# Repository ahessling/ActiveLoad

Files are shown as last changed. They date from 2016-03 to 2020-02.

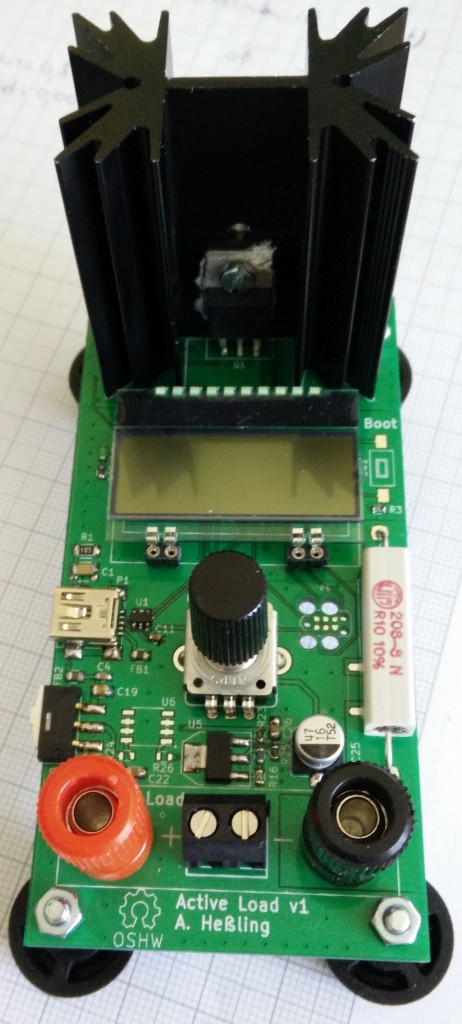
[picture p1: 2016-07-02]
active-load-v1-top.jpg

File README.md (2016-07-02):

# Active Load with microcontroller
This repository contains the hardware design, the firmware and the GUI software of my active load device.



Features:
* Power supply from around 3.3V to 40V
* Should be powered by device under test
* Alternative power supply via USB
* Maximum dissipated power: Around 12W permanently at room temperature
* Maximum current: 3A
* Robust (protected from overvoltage, overcurrent and overtemperature conditions)
* Device under test should be connected via banana plugs or screw terminals
* A PC should be able to monitor the actual current and control the desired current via USB
* Small display to monitor actual and setpoint current
* Rotary encoder to change setpoint current
* Small (5×10 cm)
* Measure temperature at heatsink

The whole design process with a lot of details are written down [in my blog](http://blog.andrehessling.de/2016/02/07/project-active-load-with-microcontroller-part-1-requirements/).

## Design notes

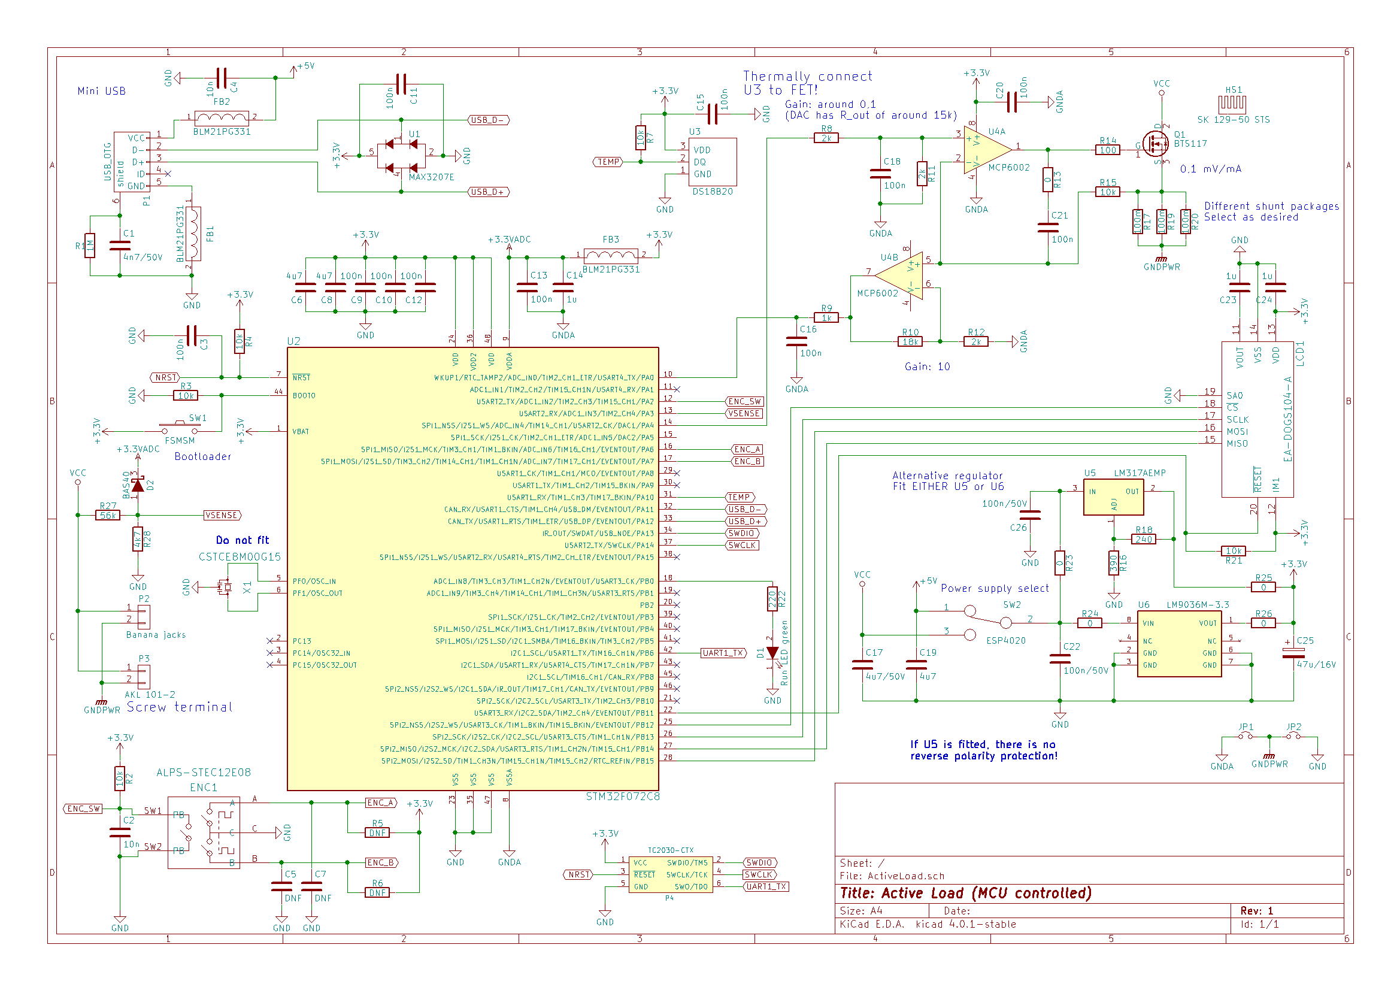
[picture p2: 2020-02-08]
Hardware/Schematic/Export/ActiveLoad_v1-schematic.png

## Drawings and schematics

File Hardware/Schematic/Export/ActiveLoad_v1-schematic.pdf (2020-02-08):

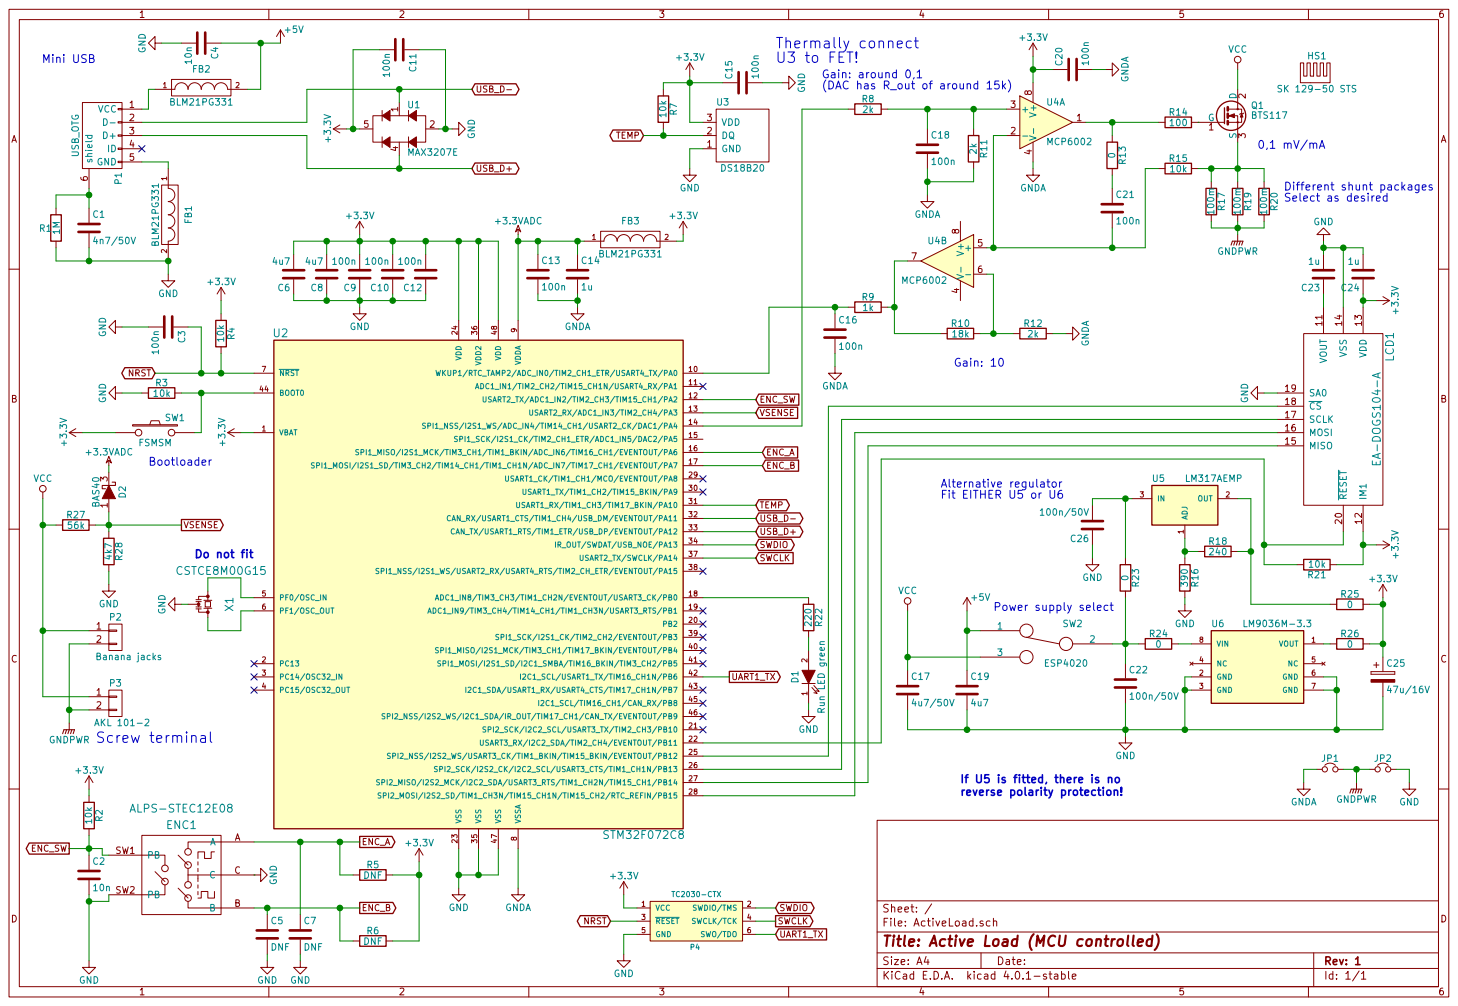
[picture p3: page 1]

reverse polarity protection! Do not fit
CSTCE8M00G15 GND

0 Power supply select GNDPWR

1 2 D1 Run LED green 220 R22 GND

If U5 is fitted, there is no

Id: 1/1 Title: Active Load (MCU controlled) File: ActiveLoad.sch Sheet: /

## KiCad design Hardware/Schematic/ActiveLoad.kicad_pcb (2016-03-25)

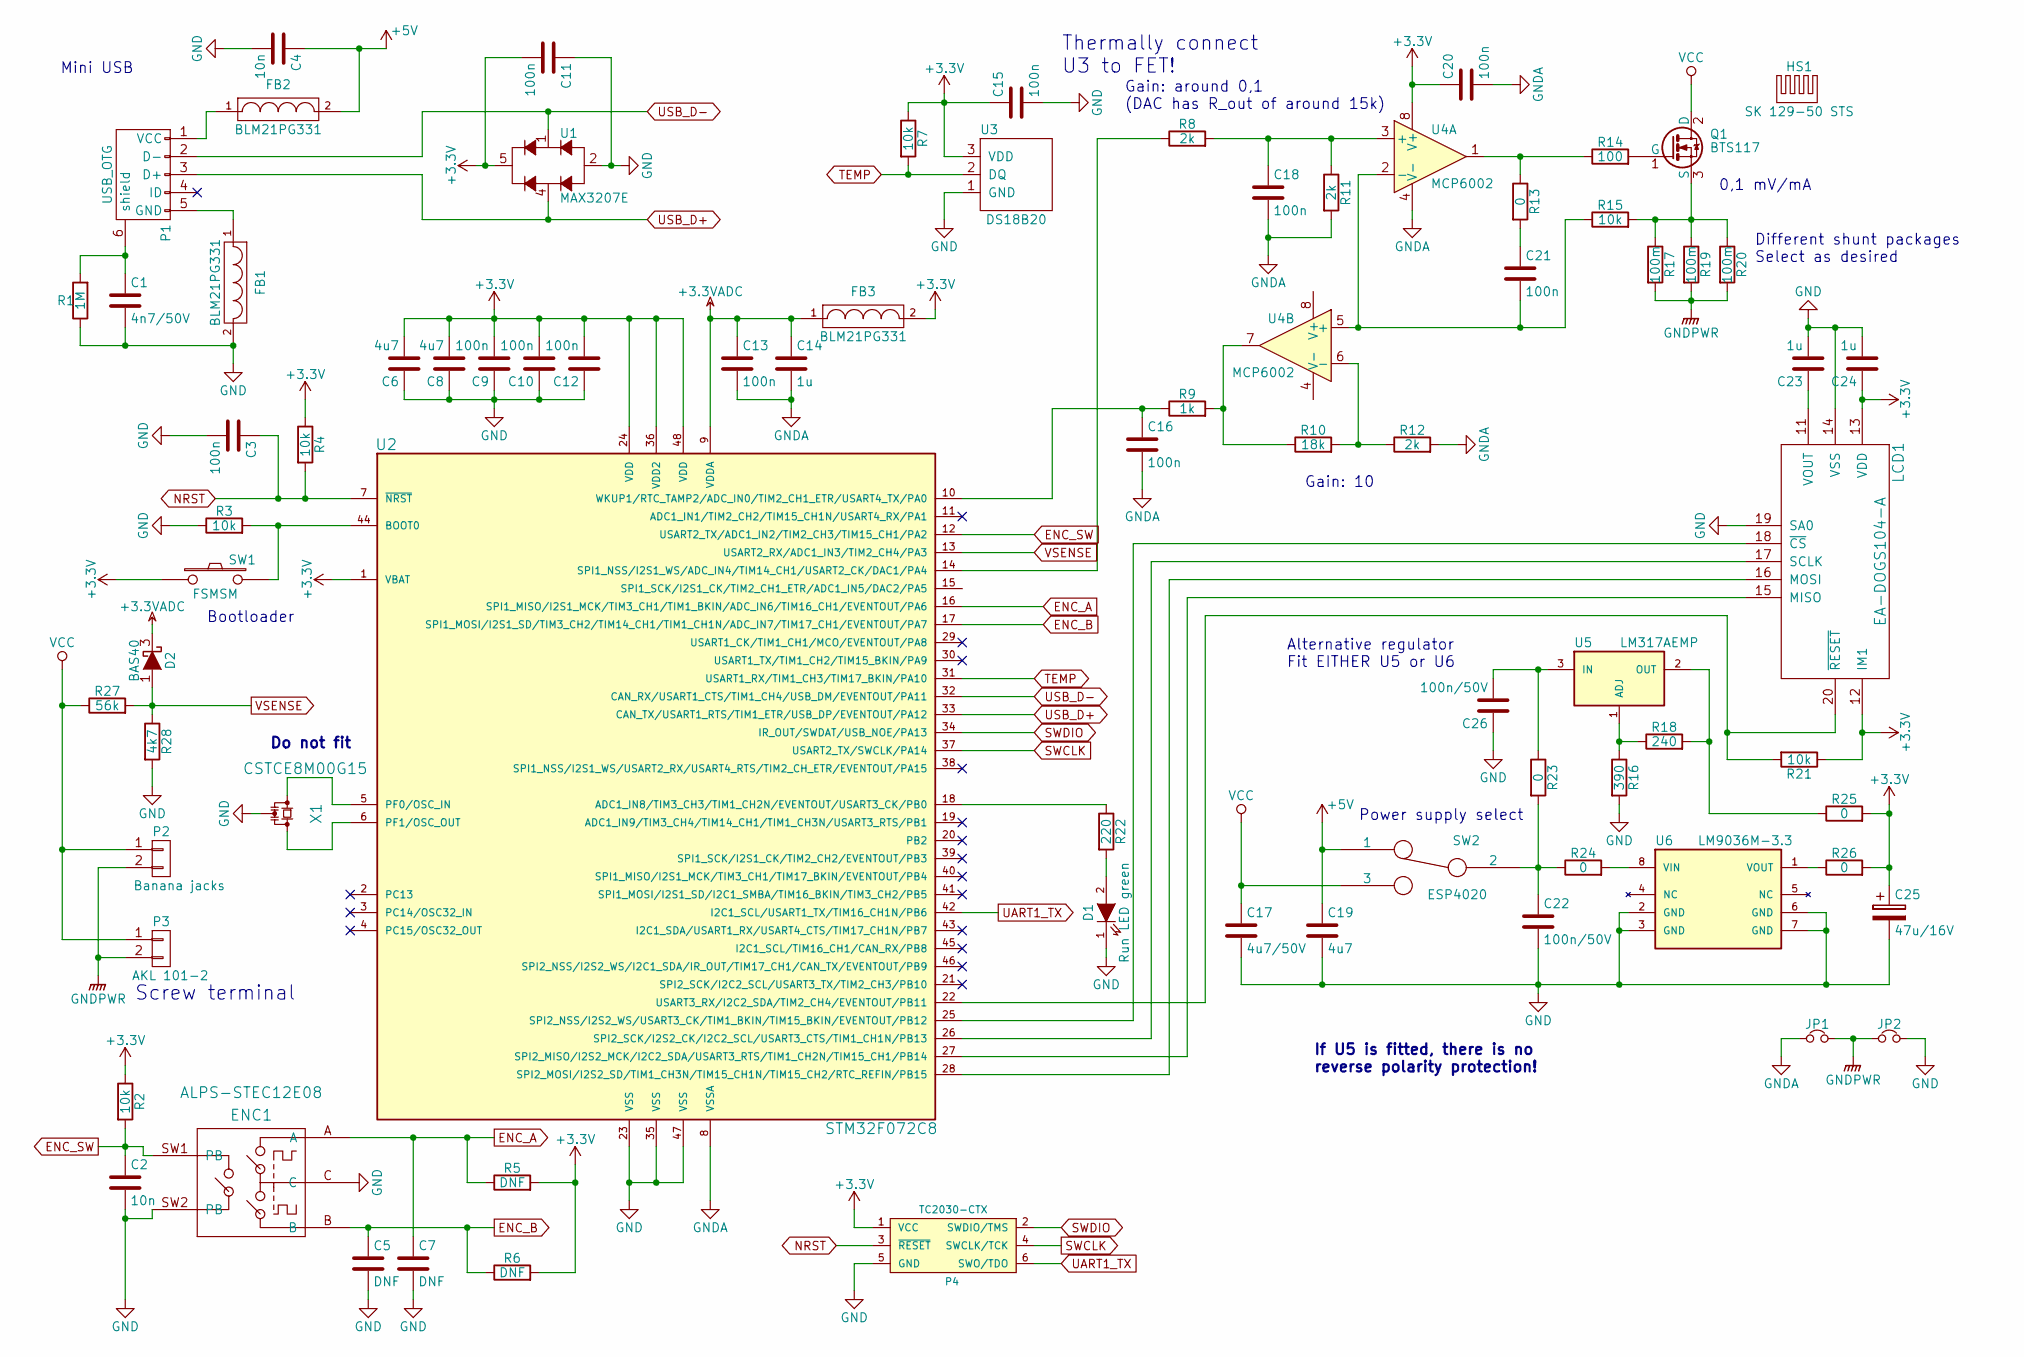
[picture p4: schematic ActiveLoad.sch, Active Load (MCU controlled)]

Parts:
C1: 4n7/50V; C_1210
C2, C4: 10n; C_0603
C3, C9, C10, C11, C12, C13, C15, C16, C18, C20, C21: 100n; C_0603
C5, C7: DNF; C_0603
C6, C8, C19: 4u7; C_0805
C14, C23, C24: 1u; C_0603
C17: 4u7/50V; C_1206
C22, C26: 100n/50V; C_0805
C25: 47u/16V; c_elec_6.3x5.3
D1: Run LED green; LED_0603
D2: BAS40; SOT-23
ENC1: ALPS-STEC12E08
FB1, FB2, FB3: BLM21PG331; R_0805
HS1: SK 129-50 STS; Heatsink_Fischer_SK129-STS_42x25mm_2xDrill2.5mm
JP1, JP2: Jumper_NC_Small; NetTie-I_Connected_SMD
LCD1: EA-DOGS104-A; DOGS104
P1: USB_OTG; USB_Mini-B
P2: Banana jacks; Banana_Jack_2Pin
P3: AKL 101-2; mors_2p
P4: TC2030-CTX; TC2030_SMALL
Q1: BTS117; TO-220_Neutral123_Vertical
R1: 1M; R_1206
R2, R3, R4, R7, R15, R21: 10k; R_0603
R5, R6: DNF; R_0603
R8, R11, R12: 2k; R_0603
R9: 1k; R_0603
R10: 18k; R_0603
R13, R23, R24, R25, R26: 0; R_0603
R14: 100; R_0603
R16: 390; R_0603
R17, R20: 100m; R_2512
R18: 240; R_0603
R19: 100m; Resistor_Cement_Horizontal_Meggitt-SBC-2
R22: 220; R_0603
R27: 56k; R_0603
R28: 4k7; R_0603
SW1: FSMSM; SW_SPST_FSMSM
SW2: ESP4020; ESP40XX
U1: MAX3207E; SOT-23-6
U2: STM32F072C8; LQFP-48_7x7mm_Pitch0.5mm
U3: DS18B20; TO-92_Inline_Narrow_Oval
U4: MCP6002; SOIC-8_3.9x4.9mm_Pitch1.27mm
U5: LM317AEMP; SOT-223
U6: LM9036M-3.3; SOIC-8_3.9x4.9mm_Pitch1.27mm
X1: CSTCE8M00G15; CSTCE_G15C

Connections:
+3.3VADC: C13.1, C14.1, D2.3 (K), FB3.1, U2.9 (VDDA)
+3V3: C6.2, C8.2, C9.2, C10.2, C11.2, C12.2, C15.1, C20.1, C24.1, C25.1, FB3.2, LCD1.12 (IM1), LCD1.13 (VDD), P4.1 (VCC), R2.1, R4.1, R5.2, R6.2, R7.1, R21.1, R25.2, R26.2, SW1.1, U1.5 (VCC), U2.1 (VBAT), U2.24 (VDD), U2.36 (VDD2), U2.48 (VDD), U3.3 (VDD), U4.8 (V+)
+5V: C4.1, C19.1, FB2.2, SW2.1
ENC_A: C7.1, ENC1.A, R5.1, U2.16 (SPI1_MISO/I2S1_MCK/TIM3_CH1/TIM1_BKIN/A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)
ENC_B: C5.1, ENC1.B, R6.1, U2.17 (SPI1_MOSI/I2S1_SD/TIM3_CH2/TIM14_CH1/TI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)
ENC_SW: C2.1, ENC1.SW1 (PB), R2.2, U2.12 (USART2_TX/ADC1_IN2/TIM2_CH3/TIM15_CH1/P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)
GND: C1.2, C2.2, C3.2, C4.2, C5.2, C6.1, C7.2, C8.1, C9.1, C10.1, C11.1, C12.1, C15.2, C17.2, C19.2, C22.2, C23.2, C24.2, C25.2, C26.1, D1.1 (K), ENC1.C, ENC1.SW2 (PB), FB1.2, JP2.2, LCD1.14 (VSS), LCD1.19 (SA0), P4.5 (GND), R1.1, R3.1, R16.2, R28.2, U1.2 (GND), U2.23 (VSS), U2.35 (VSS), U2.47 (VSS), U3.1 (GND), U6.2 (GND), U6.3 (GND), U6.6 (GND), U6.7 (GND), X1.2
GNDA: C13.2, C14.2, C16.2, C18.2, C20.2, JP1.1, R11.2, R12.2, U2.8 (VSSA), U4.4 (V-)
GNDPWR: JP1.2, JP2.1, P2.2, P3.2, R17.2, R19.2, R20.2
NRST: C3.1, P4.3 (~RESET~), R4.2, U2.7 (~NRST)
unnamed: C1.1, P1.6 (shield), R1.2
unnamed: C16.1, R9.1, U2.10 (WKUP1/RTC_TAMP2/ADC_IN0/TIM2_CH1_ETR/US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)
unnamed: C18.1, R8.2, R11.1, U4.3 (+)
unnamed: C21.1, R13.2
unnamed: C21.2, R15.1, U4.2 (-), U4.5 (+)
unnamed: C22.1, R23.2, R24.1, SW2.2
unnamed: C23.1, LCD1.11 (VOUT)
unnamed: C26.2, R23.1, U5.3 (IN)
unnamed: D1.2 (A), R22.2
unnamed: FB1.1, P1.5 (GND)
unnamed: FB2.1, P1.1 (VCC)
unnamed: LCD1.15 (MISO), U2.27 (SPI2_MISO/I2S2_MCK/I2C2_SDA/USART3_RTS/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)
unnamed: LCD1.16 (MOSI), U2.28 (SPI2_MOSI/I2S2_SD/TIM1_CH3N/TIM15_CH1N/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)
unnamed: LCD1.17 (SCLK), U2.26 (SPI2_SCK/I2S2_CK/I2C2_SCL/USART3_CTS/TI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)
unnamed: LCD1.18 (~CS~), U2.25 (SPI2_NSS/I2S2_WS/USART3_CK/TIM1_BKIN/TI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)
unnamed: LCD1.20 (~RESET~), R21.2, U2.22 (USART3_RX/I2C2_SDA/TIM2_CH4/EVENTOUT/PB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)
unnamed: Q1.1 (G), R14.2
unnamed: Q1.3 (S), R15.2, R17.1, R19.1, R20.1
unnamed: R3.2, SW1.2, U2.44 (BOOT0)
unnamed: R8.1, U2.14 (SPI1_NSS/I2S1_WS/ADC_IN4/TIM14_CH1/USAR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)
unnamed: R9.2, R10.1, U4.7
unnamed: R10.2, R12.1, U4.6 (-)
unnamed: R13.1, R14.1, U4.1
unnamed: R16.1, R18.1, U5.1 (ADJ)
unnamed: R18.2, R25.1, U5.2 (OUT)
unnamed: R22.1, U2.18 (ADC1_IN8/TIM3_CH3/TIM1_CH2N/EVENTOUT/US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)
unnamed: R24.2, U6.8 (VIN)
unnamed: R26.1, U6.1 (VOUT)
unnamed: U2.5 (PF0/OSC_IN), X1.1
unnamed: U2.6 (PF1/OSC_OUT), X1.3
SWCLK: P4.4 (SWCLK/TCK), U2.37 (USART2_TX/SWCLK/PA14)
SWDIO: P4.2 (SWDIO/TMS), U2.34 (IR_OUT/SWDAT/USB_NOE/PA13)
TEMP: R7.2, U2.31 (USART1_RX/TIM1_CH3/TIM17_BKIN/PA10), U3.2 (DQ)
UART1_TX: P4.6 (SWO/TDO), U2.42 (I2C1_SCL/USART1_TX/TIM16_CH1N/PB6)
USB_D+: P1.3 (D+), U1.4 (I/O2), U2.33 (CAN_TX/USART1_RTS/TIM1_ETR/USB_DP/EVENT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)
USB_D-: P1.2 (D-), U1.1 (I/O1), U2.32 (CAN_RX/USART1_CTS/TIM1_CH4/USB_DM/EVENT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)
VCC: C17.1, P2.1, P3.1, Q1.2 (D), R27.1, SW2.3
VSENSE: D2.1 (A), R27.2, R28.1, U2.13 (USART2_RX/ADC1_IN3/TIM2_CH4/PA3)

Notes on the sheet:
Mini USB
Bootloader
0,1 mV/mA
Gain: 10
Gain: around 0,1 (DAC has R_out of around 15k)
Screw terminal
Thermally connect U3 to FET!
Alternative regulator Fit EITHER U5 or U6
Different shunt packages Select as desired
Power supply select
If U5 is fitted, there is no reverse polarity protection!
Do not fit

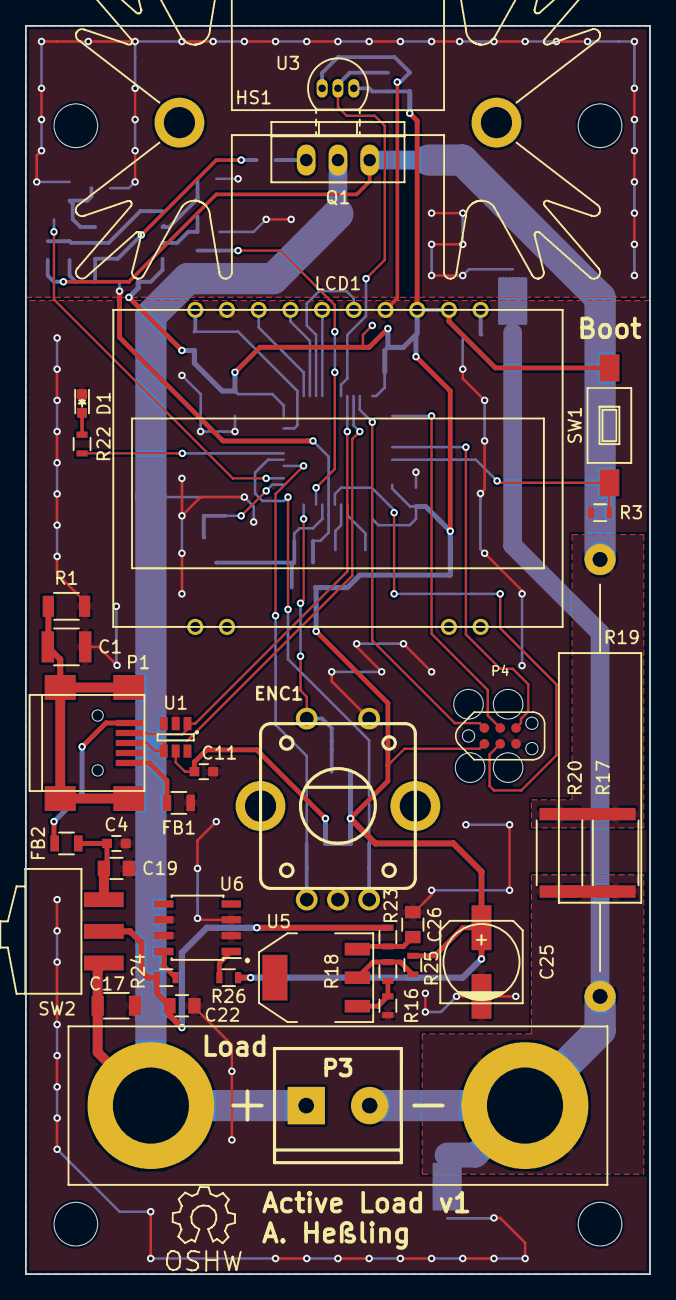
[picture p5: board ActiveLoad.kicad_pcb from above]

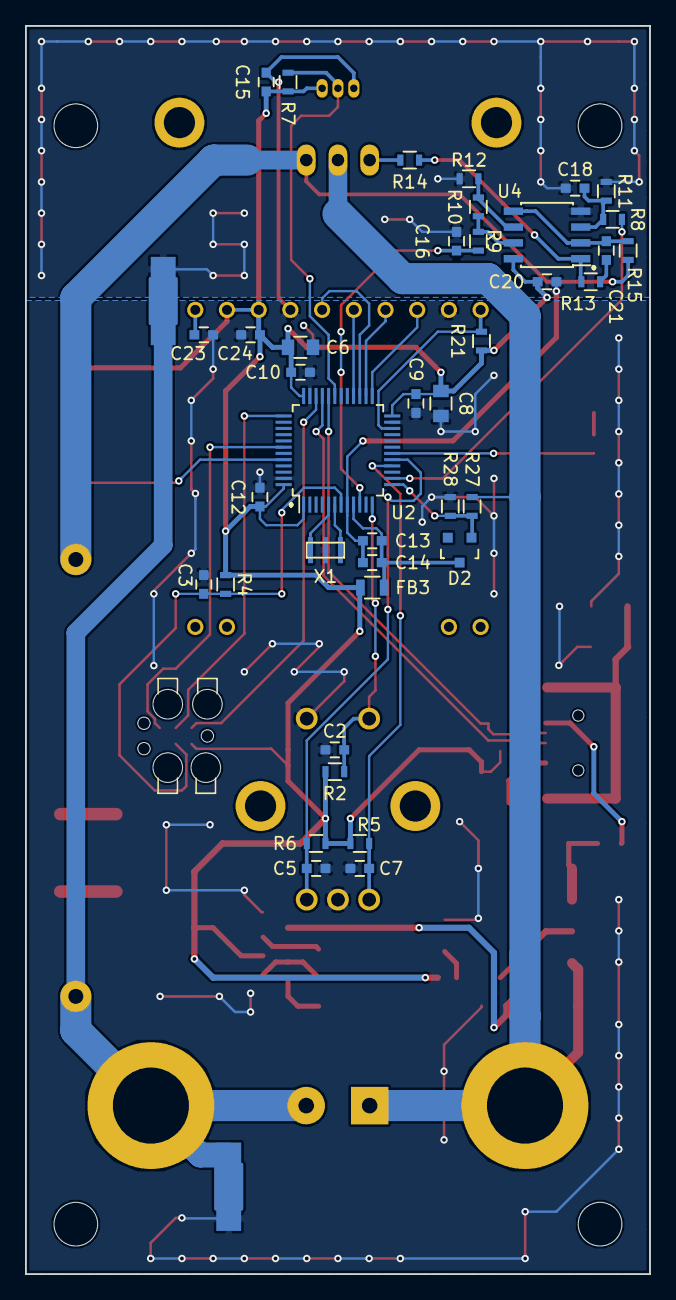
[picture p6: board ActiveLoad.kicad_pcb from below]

Board: 2 copper layers, 50.0 x 100.0 mm, 78 parts (41 on the bottom side), 48 nets.

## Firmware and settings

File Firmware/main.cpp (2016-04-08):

/** $Id:  $
  * \file
  * \author  $Author:  $
  * \version $Revision:  $
  * \package ActiveLoad
  *
  *
  *
  * (C) 2015 by André Heßling
  */

/*----------------------------------------------------------------------------*\
** Include files                                                              **
**                                                                            **
\*----------------------------------------------------------------------------*/
#include "hw_config.h"
#include "systimer.h"
#include <stdio.h>
#include <string.h>
#include "driver/spiF0.hpp"
#include "modules/HMI_USB.hpp"
#include "modules/OutputControl.hpp"
#include "modules/InputSense.hpp"
#include "modules/NVRAM.hpp"
#include "modules/HMI_Front.hpp"


#ifdef SEMIHOST
#include <stdio.h>
extern void  initialise_monitor_handles(void);
#endif

/*----------------------------------------------------------------------------*\
** Definitions                                                                **
**                                                                            **
\*----------------------------------------------------------------------------*/


/*----------------------------------------------------------------------------*\
** Variables                                                                  **
**                                                                            **
\*----------------------------------------------------------------------------*/


/*----------------------------------------------------------------------------*\
** Functions                                                                  **
**                                                                            **
\*----------------------------------------------------------------------------*/

static void enableWatchdog(void)
{
  IWDG_WriteAccessCmd(IWDG_WriteAccess_Enable);

  // IWDG counter clock: LSI/32 (LSI = 40 kHz)
  IWDG_SetPrescaler(IWDG_Prescaler_32);

  // IWDG timeout of around 250 ms
  IWDG_SetReload(312);

  // reload and enable
  IWDG_ReloadCounter();
  IWDG_Enable();
}

int main(void)
{
  mstimer_init();
  ustimer_init();

  // Wait some time for LCD to power up
  delay_ms(100);

  // enable watchdog
  enableWatchdog();

  RCC->AHBENR |= RCC_AHBPeriph_GPIOA | RCC_AHBPeriph_GPIOB | RCC_AHBPeriph_GPIOC | RCC_AHBPeriph_GPIOD;

  // low level hardware modules
  SPI spiDisplay(DISPLAY_SPI);

  // modules
  NVRAM nvRAM;
  SystemState systemState(&nvRAM);
  SystemCommand systemCommand(&nvRAM);
  OutputControl outputControl;
  InputSense inputSense;
  HMI_USB hmiUSB(&nvRAM);
  HMI_Front hmiFront(&spiDisplay);

  for (;;)
  {
    // Module: Input sense (get actual system state)
    inputSense.execute(systemCommand, systemState);

    // Module: USB interface
    hmiUSB.execute(systemState, systemCommand);

    // Module: HMI Front (display and rotary encoder)
    hmiFront.execute(systemState, systemCommand);

    // Module: Output control
    outputControl.execute(systemState, systemCommand);

    // reload watchdog
    IWDG_ReloadCounter();
  }

  return 0;
}

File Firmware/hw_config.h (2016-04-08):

/** $Id:  $
  * \file
  * \author  $Author:  $
  * \version $Revision:  $
  * \package ActiveLoad
  *
  *
  *
  * (C) 2014 by André Heßling
  */

#ifndef HW_CONFIG_H_
#define HW_CONFIG_H_

/*----------------------------------------------------------------------------*\
** Include files                                                              **
**                                                                            **
\*----------------------------------------------------------------------------*/
#include "stm32f0xx.h"
#include "stm32f0xx_conf.h"

#ifdef __cplusplus
#define EXTERN extern "C"
#else
#define EXTERN
#endif

/*----------------------------------------------------------------------------*\
** Definitions                                                                **
**                                                                            **
\*----------------------------------------------------------------------------*/
/** @addtogroup /ActiveLoad/hw_config.h
  * @{
  */

#define USE_SHELL

#ifdef USE_SHELL
#define SHELL_INTERACTIVE
#define SHELL_USART 1
#define SHELL_BAUDRATE 115200
#endif

#define USB_CLOCK_SOURCE_CRS
#define USB_IT_PRIO                    1

// Display
#define DISPLAY_SPI             SPI2
#define DISPLAY_SPI_AF          GPIO_AF_0
//#define DAC_SPI_PRESCALER
#define DISPLAY_SCK_PORT        GPIOB
#define DISPLAY_SCK_PIN         GPIO_Pin_13
#define DISPLAY_SCK_SOURCE      GPIO_PinSource13
#define DISPLAY_MISO_PORT       GPIOB
#define DISPLAY_MISO_PIN        GPIO_Pin_14
#define DISPLAY_MISO_SOURCE     GPIO_PinSource14
#define DISPLAY_MOSI_PORT       GPIOB
#define DISPLAY_MOSI_PIN        GPIO_Pin_15
#define DISPLAY_MOSI_SOURCE     GPIO_PinSource15
#define DISPLAY_CS_PORT         GPIOB
#define DISPLAY_CS_PIN          GPIO_Pin_12
#define DISPLAY_RESET_PORT      GPIOB
#define DISPLAY_RESET_PIN       GPIO_Pin_11

// Internal ADC (actual voltage)
#define ADC_VOLTAGE_CHANNEL     ADC_Channel_3
#define ADC_VOLTAGE_PORT        GPIOA
#define ADC_VOLTAGE_PIN         GPIO_Pin_3
#define ADC_VOLTAGE_SOURCE      GPIO_PinSource3
#define ADC_CURRENT_CHANNEL     ADC_Channel_0
#define ADC_CURRENT_PORT        GPIOA
#define ADC_CURRENT_PIN         GPIO_Pin_0
#define ADC_CURRENT_SOURCE      GPIO_PinSource0
#define ADC_DMA                 DMA1
#define ADC_DMA_CHANNEL         DMA1_Channel1

// Internal DAC (setpoint current)
#define DAC_CURRENT_PORT        GPIOA
#define DAC_CURRENT_PIN         GPIO_Pin_4
#define DAC_CURRENT_SOURCE      GPIO_PinSource4

// Temperature sensors (DS18B20)
#define DS18B20_POWER_PORT      GPIOA
#define DS18B20_POWER_PIN       GPIO_Pin_10

// Rotary encoder
#define ENCODER_A_PORT          GPIOA
#define ENCODER_A_PIN           GPIO_Pin_6
#define ENCODER_A_SOURCE        GPIO_PinSource6
#define ENCODER_B_PORT          GPIOA
#define ENCODER_B_PIN           GPIO_Pin_7
#define ENCODER_B_SOURCE        GPIO_PinSource7
#define ENCODER_SWITCH_PORT     GPIOA
#define ENCODER_SWITCH_PIN      GPIO_Pin_2
#define ENCODER_TIM             TIM3
#define ENCODER_AF              GPIO_AF_1

// LED
#define LED_STATE_PORT          GPIOB
#define LED_STATE_PIN           GPIO_Pin_0

/*----------------------------------------------------------------------------*\
** Structures                                                                 **
**                                                                            **
\*----------------------------------------------------------------------------*/


/*----------------------------------------------------------------------------*\
** Variables                                                                  **
**                                                                            **
\*----------------------------------------------------------------------------*/


/*----------------------------------------------------------------------------*\
** Function prototypes                                                        **
**                                                                            **
\*----------------------------------------------------------------------------*/
void jump_to(uint32_t appaddr);

/**
  * @}
  */

#endif /* HW_CONFIG_H_ */

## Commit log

2016-01-17 feat: created KiCAD base project
    [ActiveLoad.kicad_pcb, ActiveLoad.sch]
2016-01-17 feat: added devices BTS117, LM9036M and STM32F072C8
    [ActiveLoad.sch]
2016-02-01 updated schematic
    [ActiveLoad.sch]
2016-02-02 updated schematic added DOG display library
    [ActiveLoad.sch]
2016-02-04 (nearly) finished schematic
    [ActiveLoad.sch]
2016-02-05 finished schematic
    [ActiveLoad.sch]
2016-02-06 updated schematic PCB work
    [ActiveLoad.kicad_pcb, ActiveLoad.sch]
2016-02-07 updated schematic (TEMP pin and LED pin) finished PCB
    [ActiveLoad.kicad_pcb, ActiveLoad.sch]
2016-02-07 updated schematic and PCB (added VSENSE)
    [ActiveLoad.kicad_pcb, ActiveLoad.sch]
2016-02-08 changed Gerber export settings PCB finished and exported
    [ActiveLoad.kicad_pcb]
2016-02-12 fix: changed R8 and R11 to 18k and 2k to get a gain of 0,1
    [ActiveLoad.kicad_pcb, ActiveLoad.sch]
2016-02-14 feat: prepare encoder interface
2016-02-15 feat: encoder working with differen timer clock settings and filter, debug output code for now
2016-02-18 feat: new function stepSetpointCurrent to step up/down setpoint current feat: encoder steps are evaluated and setpoint current changes accordingly fix: needed mA to A conversion in HMI_USB fix: setpo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
    [HMI_Front.cpp, SystemCommand.hpp]
2016-02-18 feat: implemented actual voltage calibration
2016-02-18 feat: implemented actual/setpoint current calibration
2016-02-18 feat: memory slots can be read from flash feat: parameter section in flash (at the end)
2016-02-24 feat: initial commit of DOGS104 with SPI interface feat: gpio.h helper struct to integrate a GPIO port and pin
2016-02-24 feat: HMI_Front module now includes DOGS104_SPI device
2016-02-25 feat: actual power is calculated feat: overloaded relational operators == and != of SystemState
2016-02-25 feat: display is updated when the system state changes (but only every 100 ms) feat: printf can now use floats
2016-02-28 refactor: use MCP6002 (and not MCP6442 which does NOT have a better performance) fix: replaced 8,2µH/0805 inductors with BLM21PG331 EMI ferrite filters
    [ActiveLoad.kicad_pcb, ActiveLoad.sch]
2016-03-01 feat: LCD now supports double buffering using a framebuffer feat: only the changed data are written when double buffering is enabled
2016-03-02 fix: cursor must be manually moved to new lines if the framebuffer is written to the LCD memory due to the addressing scheme
2016-03-02 fix: cursor position needed to be set to zero if display is cleared refactor: DOG display lines now configurable from 1 to 4 fix: reworked the LCD init function to (hopefully) set all registers corre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
    [HMI_Front.cpp]
2016-03-13 feat: added getter functions to read system state of device feat: added setter functions to set system state of device feat: added function to find all active load devices
2016-03-13 fix: device was not always being closed while searching for a device
2016-03-17 fix: disable DAC output buffer because of minimum low output voltage (~200 mV). Output impedance is around 15k which means that the voltage divider may need adjustment.
2016-03-18 refactor: change reset delay to 20 ms feat: support for display read operation fix: completely wrong SPI data format: LSB first and 3 bytes per transfer needed fix: after calling spi.reconfigure, eve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
    [DOGS104_SPI.cpp]
2016-03-19 fix: reconfigure SPI by resetting the peripheral via RCC command fix: deinit should disable the peripheral clock
    [spiF0.cpp]
2016-03-19 refactor: spi.reconfigure is now called again
2016-03-19 fix: start of application should be delayed so that LCD can power up
    [main.cpp]
2016-03-19 change: output string of measured voltage
2016-03-19 feat: initial temperature reading when application starts
2016-03-20 fix: setpoint and actual current cannot be negative (can happen if calibrated)
    [InputSense.cpp]
2016-03-20 fix: SystemCommand did not load NVRAM settings
    [main.cpp]
2016-03-20 fix: due to internal resistance of unbuffered DAC output (~15k), R8 is lowered to 2k
    [ActiveLoad.kicad_pcb, ActiveLoad.sch]
2016-03-21 feat: added function to set new setpoint current while taking system limits into account feat: output "value out of range error" if an invalid setpoint current is given via USB
    [SystemCommand.hpp]
2016-03-21 feat: minimize current draw if setpoint current is 0 by switching DAC off
2016-03-21 feat: detect overtemperature condition if temperature is above 70 degree Celsius feat: blink last display line during overtemperature conditions cleanup: remove _lastSystemState and update display ev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
2016-03-21 feat: LED shows system state (blinks slowly if setpoint and actual current differ, blinks fast when overtemperature)
2016-03-22 feat: if encoder key is pressed, reset to safe state (setpoint current to 0)
    [HMI_Front.cpp]
2016-03-22 doc: added note that LM317 has no reverse polarity protection
    [ActiveLoad.sch]
2016-03-23 feat: unknown/invalid temperatures are now displayed as "?" fix: correct rounding using roundf feat: MEAS:TEMP? now displays temperature with one decimal place
    [HMI_Front.cpp, InputSense.cpp]
2016-03-23 feat: add MEAS:POWer? query to get actual power and also add actual power to DUMP?
2016-03-24 feat: TwoPointCalibration now includes input and output vector which was used for calibration
2016-03-24 change: SCPI subsystem CALIB is now CAL feat: CAL:CURR? and CAL:VOLT? queries added to get details about the calibration data feat: CAL:CLEAR ALL, CAL:CLEAR VOLT and CAL:CLEAR CURR to selectively cle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
2016-03-24 fix: make changing of output current depend on calibrated current and not on setpoint current cleanup: _oldSystemState not needed chore: revision to 2
2016-03-25 chore: change some resistors, caps and resonator to "DNF"
    [ActiveLoad.kicad_pcb, ActiveLoad.sch]
2016-03-25 feat: encoder key now retrieves old setpoint current if it is pressed again chore: revision to 3
2016-03-26 feat: added calibration functions
2016-03-27 feat: added property IsOpen refactor: change name Open to OpenAsync refactor: OpenAsync now returns the SCPI identity object. This means that an exception is thrown if the device to be opened is not 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
2016-03-30 refactor: return null as temperature if device cannot read the current temperature (it returns a ? in this case)
2016-03-30 feat: added controls to visualize and control state of device feat: exceptions are now evaluated and proper error messages are generated
2016-03-30 doc: added property docs fix: retry once while trying to get identity object. Otherwise connect might fail sometimes, this is just a workaround because the problem is in the device firmware.
2016-03-31 feat: it is now checked if device is calibrated when the connection has been established
2016-03-31 feat: warning is displayed if device is not calibrated fix: no need to await cancellation if disconnect button is pressed
2016-03-31 refactor: rename activeLoadCancellationTokenSource to ctsRefreshTask fix: produce error in message box only if an unexpected error happened fix: no need to wait for cancellation feat: disable button 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
2016-03-31 feat: class CalibrationData with subclasses CurrentCalibration and VoltageCalibration refactor: all format specific conversions done in Calibration subclasses refactor: function GetCalibrationAsync n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
2016-04-01 feat: make last seen voltage and current available as properties refactor: make calibration data points public
2016-04-01 feat: calibration now possible via tool and extra form
2016-04-01 fix: flush buffers by sending an empy SCPI line and await answer when device is opened fix: SCPI identity object should be dissected in try-catch block
2016-04-03 feat: added property (last seen) Temperature
2016-04-03 feat: added an AboutBox chore: updated assembly info
2016-04-04 chore: set Doxygen package name correctly
    [hw_config.h, main.cpp]
2016-05-02 fix: temporarily disable the USB interrupt while communicating with the temperature sensor because it might disturb the one-wire communication
    [InputSense.cpp]
2020-02-08 doc: add pdf schematic
